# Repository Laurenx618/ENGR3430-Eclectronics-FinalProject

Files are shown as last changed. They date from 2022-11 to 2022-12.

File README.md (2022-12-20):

# ENGR3430-Eclectronics-FinalProject

## Description

This project is for the Eclectronics Final.

The final layout used was `no_connector`.

Here, we have a RPI2040 to connect to an ESP32-WROOM-32 (just for WIFI use) as well as an LCD screen in order to  connect to the internet, read someone's *Now Playing* information using the Spotify API Spotipy, and display the song on the screen. There is also a circuit for light detection, which is used to create a "light" and "dark" mode on screen. All of these are communicating with the RPI2040.

----
## Hardware Connections

* Microcontroller: RPI2040
* WiFi Module: ESP32-WROOM-32
* LCD Screen: 16x2 Serial LCD [(Amazon Link)](https://www.amazon.com/HiLetgo-HD44780-I2C1602-Interface-Backlight/dp/B07W5KC65S)

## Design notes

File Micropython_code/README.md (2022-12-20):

# Firmware

## Hardware Connections

* Microcontroller: RPI2040
* WiFi Module: ESP32-WROOM-32
* LCD Screen: 16x2 Serial LCD [Amazon Link](https://www.amazon.com/HiLetgo-HD44780-I2C1602-Interface-Backlight/dp/B07W5KC65S)

## Description

This folder includes both the tested CircuitPython and MicroPython code.

It includes the following libraries from the [CircuitPython Library Bundle](https://github.com/adafruit/Adafruit_CircuitPython_Bundle/releases):

* adafruit_bus_device
* adafruit_minimqtt
* adafruit_io
* adafruit_esp32_spi
* adafruit_requests.mpy

As well as this [ESP32SPI CircuitPython library from Adafruit](https://github.com/adafruit/Adafruit_CircuitPython_ESP32SPI).

------

Steps followed for the WIFI connection were according to this guide: [Quickstart IoT - Raspberry Pi Pico RP2040 with WIFI](https://learn.adafruit.com/quickstart-rp2040-pico-with-wifi-and-circuitpython/circuitpython-wifi)

Steps followed for the LCD screen driver included a lot of scaffolding from this video:[LCD Basics for the Pi Pico](https://youtu.be/B8Kr_3xHjqE).

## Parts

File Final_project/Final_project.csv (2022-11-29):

Collated Components:
Item | Qty | Reference(s) | Value | LibPart | Footprint | Datasheet | Digi-Key_Part
1 | 12 | C1, C2, C3, C4, C5, C6, C7, C10, C11, C15, C17, C18 | 0.1µF | Device:C | Capacitor_SMD:C_0603_1608Metric | ~ | CL10B104JB8NNNC
2 | 3 | C8, C9, C14 | 1µF | Device:C | Capacitor_SMD:C_0603_1608Metric | ~ | CL10B105KA8NNNC
3 | 3 | C12, C13, C16 | 10µF | Device:C | Capacitor_SMD:C_0603_1608Metric | ~ | GRM188R61E106KA73D
4 | 4 | D1, D3, D4, D5 | LED | Device:LED_Filled | Final_project:LTST-C170TBKT | ~ | LTST-C170TBKT
5 | 2 | D2, D6 | PWR | Device:LED_Filled | Final_project:LTST-C170TGKT | ~ | LTST-C170TGKT
6 | 1 | D7 | SWITCH | Device:LED_Filled | Final_project:LTST-C170TGKT | ~ | LTST-C170TGKT
7 | 1 | J1 | USB4105-GF-A | Eclectronics:USB4105-GF-A | Final_project:USB4105-GF-A |  | USB4105-GF-A
8 | 1 | J2 | Conn_01x04 | Connector_Generic:Conn_01x04 | Connector_PinSocket_2.54mm:PinSocket_1x04_P2.54mm_Horizontal | ~ | PPTC041LGBN-RC
9 | 1 | J4 | LEFT | Connector_Generic:Conn_01x20 | Connector_PinSocket_2.54mm:PinSocket_1x20_P2.54mm_Vertical | ~ | ~
10 | 1 | J5 | RIGHT | Connector_Generic:Conn_01x20 | Connector_PinSocket_2.54mm:PinSocket_1x20_P2.54mm_Vertical | ~ | ~
11 | 4 | R1, R2, R3, R4 | 5.1K | Device:R | Resistor_SMD:R_0603_1608Metric | ~ | ERJ-3EKF5101V
12 | 2 | R5, R6 | 27Ω | Device:R | Resistor_SMD:R_0603_1608Metric | ~
13 | 8 | R7, R8, R10, R11, R12, R13, R14, R17 | 1K | Device:R | Resistor_SMD:R_0603_1608Metric | ~ | RC0603FR-071KL
14 | 3 | R9, R15, R16 | 10K | Device:R | Resistor_SMD:R_0805_2012Metric | ~
15 | 1 | R18 | R_Photo | Device:R_Photo | Final_project:02-LDR4 | ~
16 | 1 | RV1 | LDR | Device:R_Potentiometer | Final_project:TRIM_T73YU103KT20 | ~ | TRIM_T73YU103KT20
17 | 1 | S1 | RST | Eclectronics:SW | Final_project:KXT321LHS |  | KXT321LHS
18 | 1 | S2 | BOOT | Eclectronics:SW | Final_project:KXT321LHS |  | KXT321LHS
19 | 1 | U1 | RP2040 | Eclectronics:RP2040 | Final_project:RP2040 | https://datasheets.raspberrypi.com/rp2040/rp2040-datasheet.pdf | MCP1702T-3302E&slash_CB
20 | 1 | U2 | MCP1702T-3302E_CB | Eclectronics:MCP1702T-3302E_CB | Final_project:MCP1702T-3302E&slash_CB |  | MIC_WSON-8-M
21 | 1 | U3 | W25Q128JV | Eclectronics:W25Q128JV | Final_project:MIC_WSON-8-M |  | X
22 | 1 | U4 | ESP32-WROOM-32 | ESP32-WROOM-32:ESP32-WROOM-32 | MODULE_ESP32-WROOM-32 | https://www.espressif.com/sites/default/files/documentation/esp32-wroom-32_datasheet_en.pdf | LM393D
23 | 1 | U5 | LM393D | pspice:OPAMP | Final_project:LM393D | ~ | CSTNE
24 | 1 | Y1 | 12MHz | Eclectronics:Crystal | Final_project:CSTNE

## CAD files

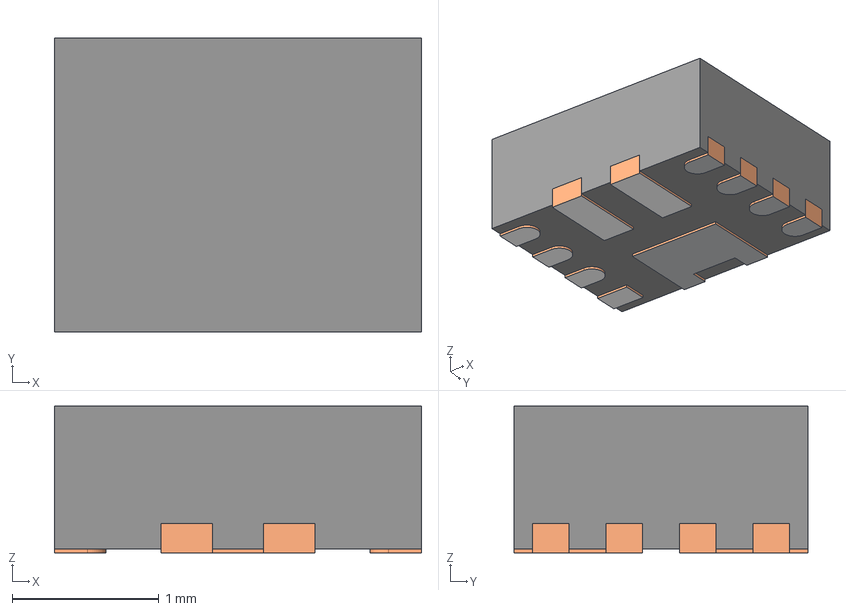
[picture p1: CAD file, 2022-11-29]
Final_project/3D/RNR0011A.stp
2.50 x 2.00 x 1.00 mm
FRAME-RNR0011A
BODY-QFN
PIN1-ID

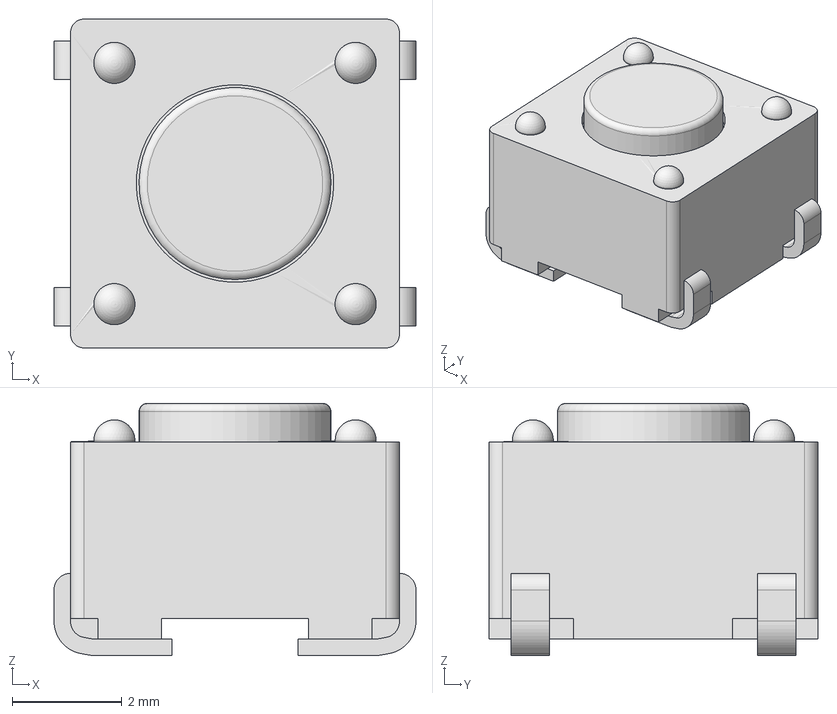
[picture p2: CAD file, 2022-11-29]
Final_project/3D/TL3301NFxxxxJ.stp
6.60 x 6.00 x 4.60 mm

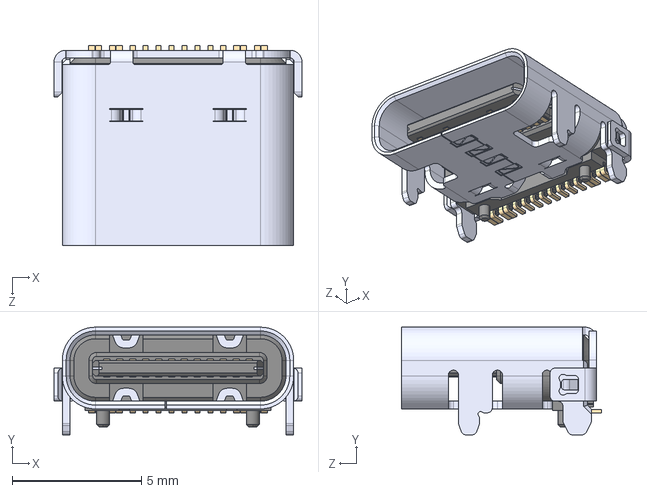
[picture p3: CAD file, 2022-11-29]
Final_project/3D/USB4105-GF-A.step
9.58 x 4.16 x 7.71 mm

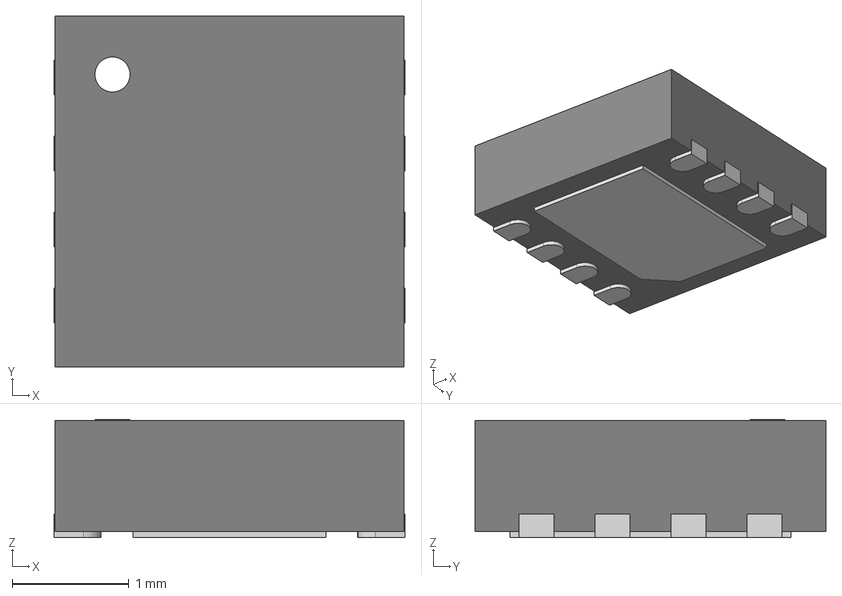
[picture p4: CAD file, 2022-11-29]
Final_project/3D/DFN8_3x3_0.65.step
3.00 x 3.00 x 1.01 mm

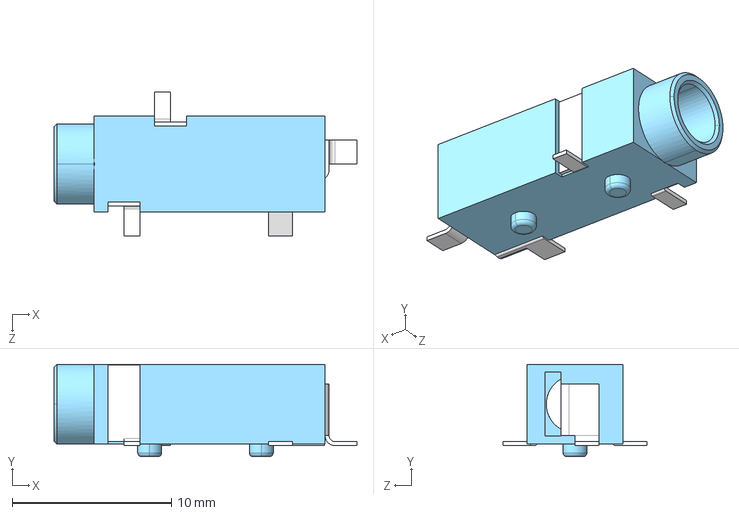
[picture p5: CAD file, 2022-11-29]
Final_project/3D/SJ-3524-SMT-TR-BE.step
19.0 x 5.80 x 9.00 mm

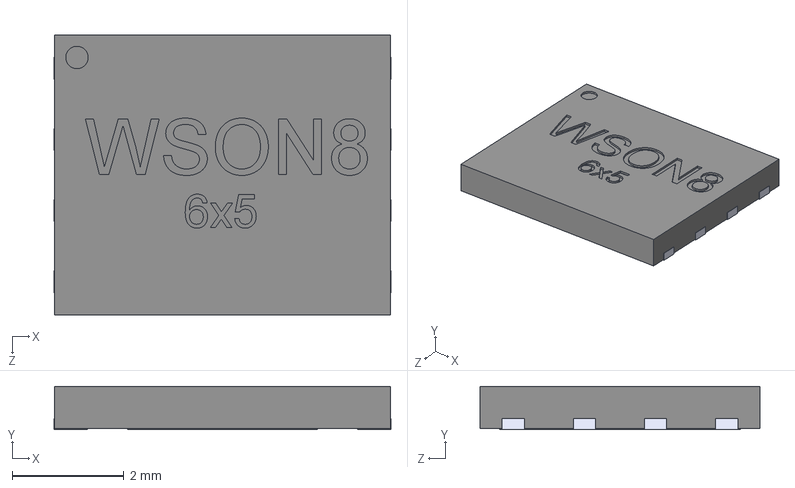
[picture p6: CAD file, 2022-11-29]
Final_project/3D/WSON8-6x5.STEP
6.02 x 0.77 x 5.00 mm

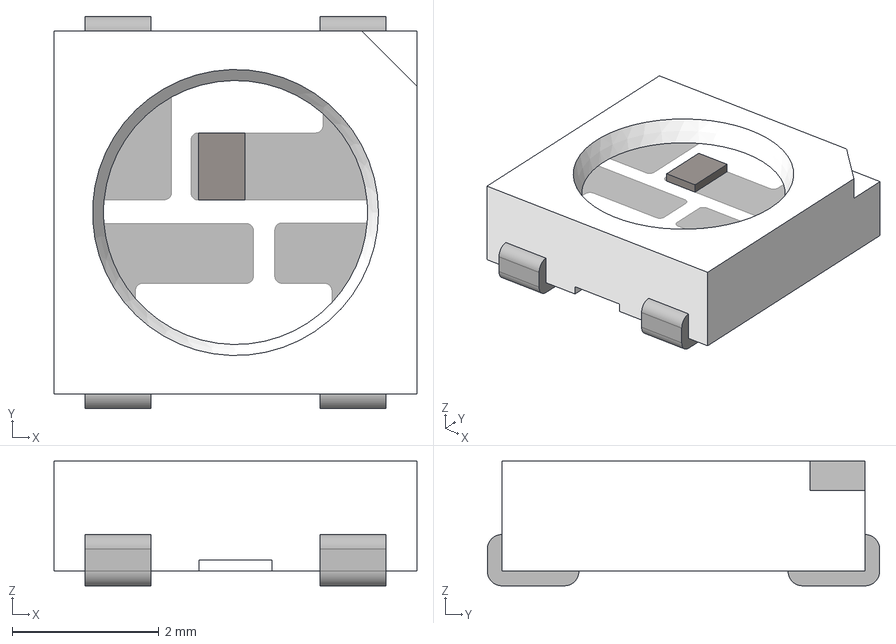
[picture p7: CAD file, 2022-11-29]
Final_project/3D/WS2812_RGB_LED_updated.stp
4.95 x 5.35 x 1.70 mm

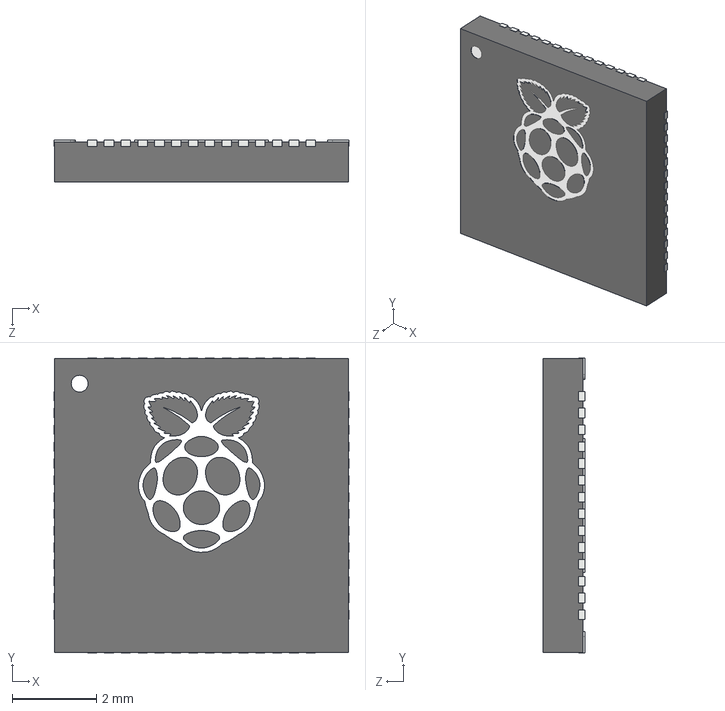
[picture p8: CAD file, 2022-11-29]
Final_project/3D/RP2040_QFN_PACKAGE.STEP
7.02 x 7.02 x 1.00 mm

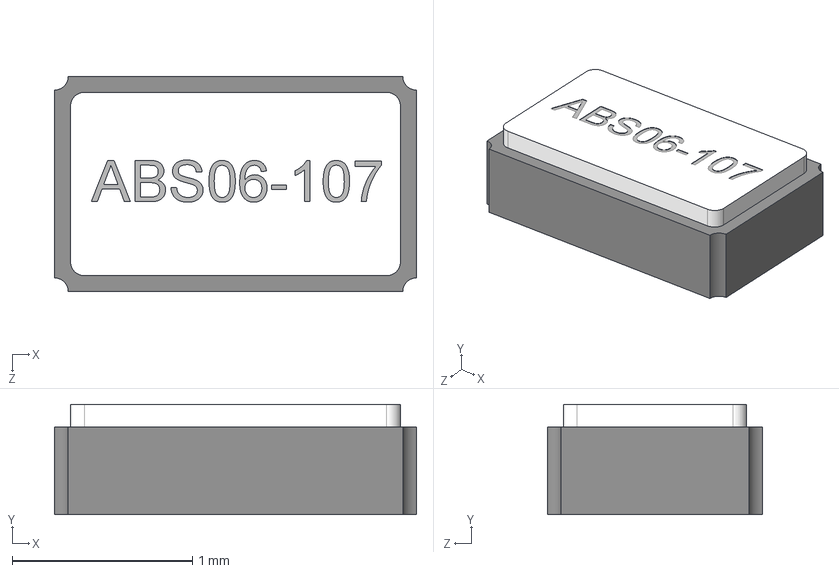
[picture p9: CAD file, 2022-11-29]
Final_project/3D/ABS06-107.STP
2.01 x 0.612 x 1.19 mm

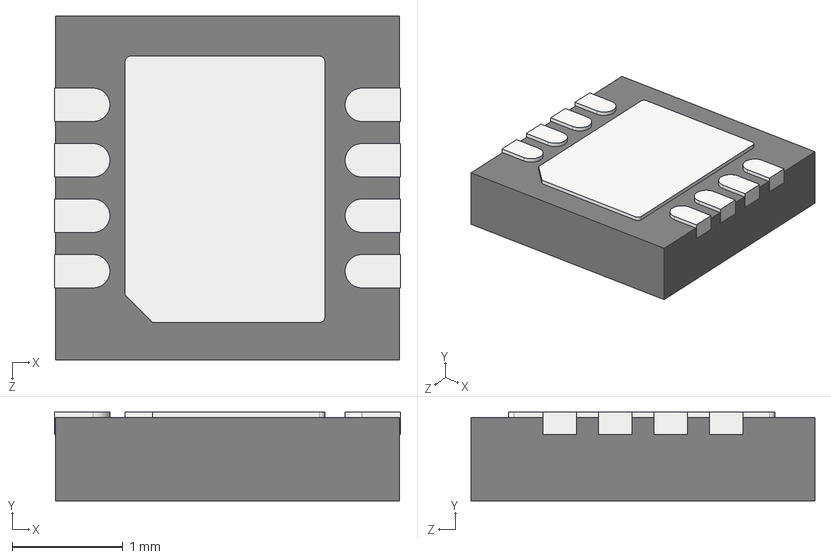
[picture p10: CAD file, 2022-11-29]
Final_project/3D/DFN-8-3x3-0_5.STEP
3.12 x 0.8 x 3.10 mm
User Library-My-DFN-8-3x3-0.5_Part 11
User Library-My-DFN-8-3x3-0.5_Body
User Library-My-DFN-8-3x3-0.5_14
User Library-My-DFN-8-3x3-0.5_13
User Library-My-DFN-8-3x3-0.5_2
User Library-My-DFN-8-3x3-0.5_1
User Library-My-DFN-8-3x3-0.5_11
User Library-My-DFN-8-3x3-0.5_3
User Library-My-DFN-8-3x3-0.5_12
User Library-My-DFN-8-3x3-0.5_4
User Library-My-DFN-8-3x3-0.5_TP

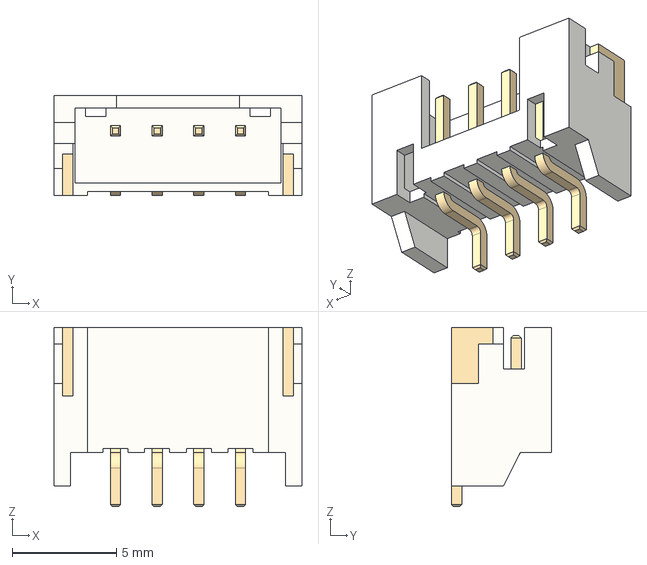
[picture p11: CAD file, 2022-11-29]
Final_project/3D/S4B-PH-SM4-TB.stp
11.9 x 4.80 x 8.60 mm

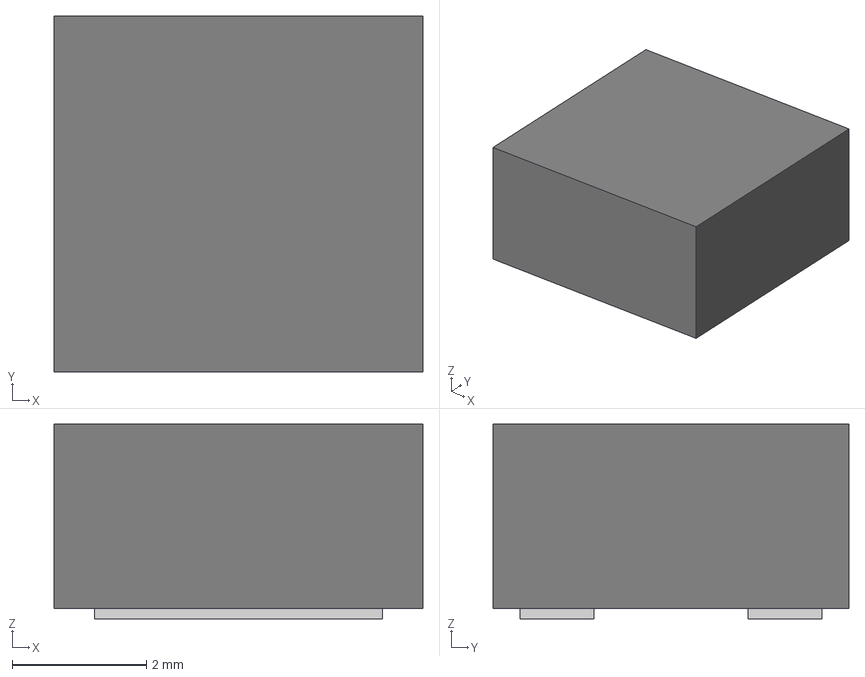
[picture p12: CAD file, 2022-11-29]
Final_project/3D/PA5003.182NLT.step
5.50 x 5.30 x 2.90 mm

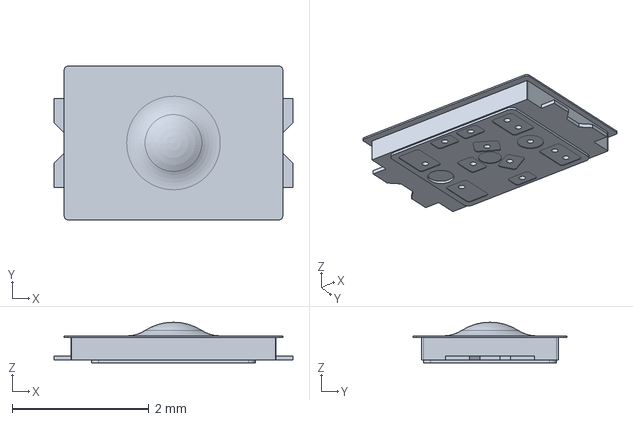
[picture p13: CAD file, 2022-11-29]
Final_project/3D/KXT321LHS.stp
3.50 x 2.25 x 0.595 mm

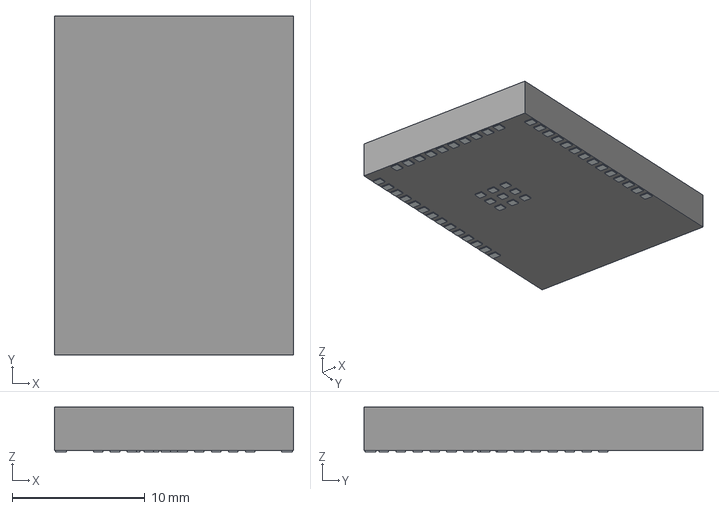
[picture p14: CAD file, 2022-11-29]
Final_project/3D/ESP32-WROOM-32D-N4.stp
18.0 x 25.5 x 3.35 mm
Pins

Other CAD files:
Final_project/3D/TL3301AFxxxxJ.stp
Final_project/3D/UFQFPN48.stp
Final_project/3D/CUI_SDS-50J.step
Final_project/3D/ABM10.STP
Final_project/3D/3382g-001-xxx.stp
Final_project/3D/CSTNE.step
Final_project/3D/QFN-32_5x5.stp
Final_project/3D/WS2812-2020.STEP

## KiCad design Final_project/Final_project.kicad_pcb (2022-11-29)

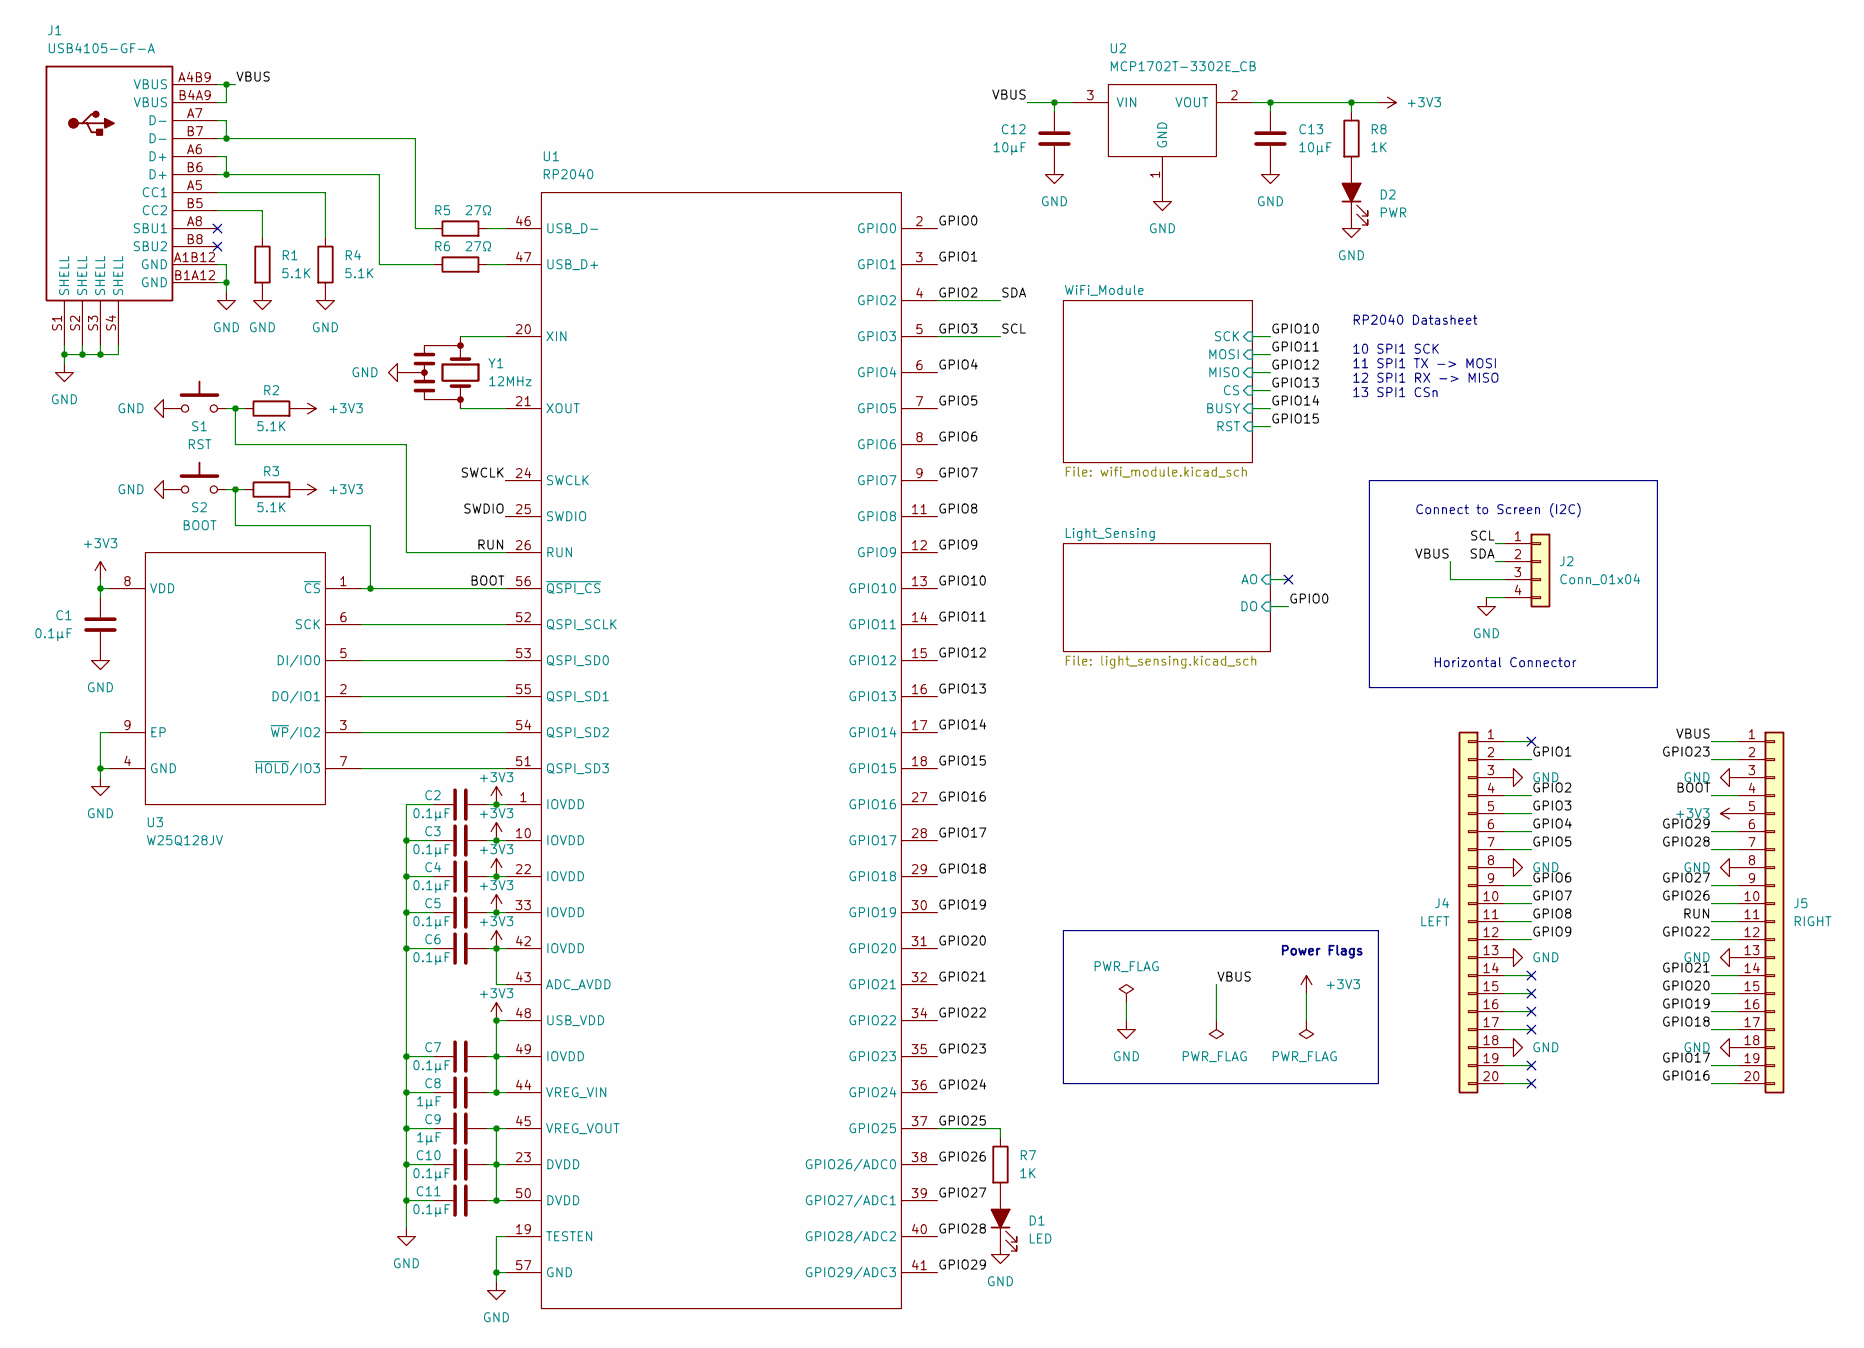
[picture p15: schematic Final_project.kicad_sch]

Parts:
C1, C2, C3: 0.1µF; C_0603_1608Metric; Digi-Key_Part CL10B104JB8NNNC
C4, C5, C6, C7, C10, C11: 0.1µF; C_0603_1608Metric
C8: 1µF; C_0603_1608Metric; Digi-Key_Part CL10B105KA8NNNC
C9: 1µF; C_0603_1608Metric
C12, C13: 10µF; C_0603_1608Metric; Digi-Key_Part GRM188R61E106KA73D
D1: LED; LTST-C170TBKT
D2: PWR; LTST-C170TGKT
J1: USB4105-GF-A
J2: Conn_01x04; PinSocket_1x04_P2.54mm_Horizontal
J4: LEFT; PinSocket_1x20_P2.54mm_Vertical
J5: RIGHT; PinSocket_1x20_P2.54mm_Vertical
R1: 5.1K; R_0603_1608Metric
R2, R4: 5.1K; R_0603_1608Metric; Digi-Key_Part ERJ-3EKF5101V
R3: 5.1K; R_0603_1608Metric; Digi-Key_Part ERJ-3EKF5101VERJ-3EKF5101V
R5: 27Ω; R_0603_1608Metric; Part RC0603FR-071KL
R6: 27Ω; R_0603_1608Metric
R7, R8: 1K; R_0603_1608Metric; Digi-Key_Part RC0603FR-071KL
S1: RST; KXT321LHS
S2: BOOT; KXT321LHS
U1: RP2040
U2: MCP1702T-3302E_CB; MCP1702T-3302E&slash_CB
U3: W25Q128JV; MIC_WSON-8-M
Y1: 12MHz; CSTNE

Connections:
+3V3: C1.2, C2.1, C3.1, C4.1, C5.1, C6.1, C7.1, C8.1, C13.1, J5.5, R2.2, R3.2, R8.1, U1.1 (IOVDD), U1.10 (IOVDD), U1.22 (IOVDD), U1.33 (IOVDD), U1.42 (IOVDD), U1.43 (ADC_AVDD), U1.44 (VREG_VIN), U1.48 (USB_VDD), U1.49 (IOVDD), U2.2 (VOUT), U3.8 (VDD); also elsewhere on the board
/BOOT: J5.4, R3.1, S2.2, U1.56 (~QSPI_CS), U3.1 (~CS)
/GPIO0: U1.2 (GPIO0); also elsewhere on the board
/GPIO1: J4.2, U1.3 (GPIO1)
/GPIO2: J2.2, J4.4, U1.4 (GPIO2)
/GPIO3: J2.1, J4.5, U1.5 (GPIO3)
/GPIO4: J4.6, U1.6 (GPIO4)
/GPIO5: J4.7, U1.7 (GPIO5)
/GPIO6: J4.9, U1.8 (GPIO6)
/GPIO7: J4.10, U1.9 (GPIO7)
/GPIO8: J4.11, U1.11 (GPIO8)
/GPIO9: J4.12, U1.12 (GPIO9)
/GPIO10: U1.13 (GPIO10); also elsewhere on the board
/GPIO11: U1.14 (GPIO11); also elsewhere on the board
/GPIO12: U1.15 (GPIO12); also elsewhere on the board
/GPIO13: U1.16 (GPIO13); also elsewhere on the board
/GPIO14: U1.17 (GPIO14); also elsewhere on the board
/GPIO15: U1.18 (GPIO15); also elsewhere on the board
/GPIO16: J5.20, U1.27 (GPIO16)
/GPIO17: J5.19, U1.28 (GPIO17)
/GPIO18: J5.17, U1.29 (GPIO18)
/GPIO19: J5.16, U1.30 (GPIO19)
/GPIO20: J5.15, U1.31 (GPIO20)
/GPIO21: J5.14, U1.32 (GPIO21)
/GPIO22: J5.12, U1.34 (GPIO22)
/GPIO23: J5.2, U1.35 (GPIO23)
/GPIO24: U1.36 (GPIO24)
/GPIO25: R7.1, U1.37 (GPIO25)
/GPIO26: J5.10, U1.38 (GPIO26/ADC0)
/GPIO27: J5.9, U1.39 (GPIO27/ADC1)
/GPIO28: J5.7, U1.40 (GPIO28/ADC2)
/GPIO29: J5.6, U1.41 (GPIO29/ADC3)
/RUN: J5.11, R2.1, S1.2, U1.26 (RUN)
/SWCLK: U1.24 (SWCLK)
/SWDIO: U1.25 (SWDIO)
/VBUS: C12.2, J1.A4B9 (VBUS), J1.B4A9 (VBUS), J2.3, J5.1, U2.3 (VIN)
GND: C1.1, C2.2, C3.2, C4.2, C5.2, C6.2, C7.2, C8.2, C9.2, C10.2, C11.2, C12.1, C13.2, D1.1 (K), D2.1 (K), J1.A1B12 (GND), J1.B1A12 (GND), J1.S1 (SHELL), J1.S2 (SHELL), J1.S3 (SHELL), J1.S4 (SHELL), J2.4, J4.3, J4.8, J4.13, J4.18, J5.3, J5.8, J5.13, J5.18, R1.2, R4.2, S1.1, S2.1, U1.19 (TESTEN), U1.57 (GND), U2.1 (GND), U3.4 (GND), U3.9 (EP), Y1.2; also elsewhere on the board
unnamed: C9.1, C10.1, C11.1, U1.23 (DVDD), U1.45 (VREG_VOUT), U1.50 (DVDD)
unnamed: D1.2 (A), R7.2
unnamed: D2.2 (A), R8.2
unnamed: J1.A5 (CC1), R4.1
unnamed: J1.A6 (D+), J1.B6 (D+), R6.1
unnamed: J1.A7 (D-), J1.B7 (D-), R5.1
unnamed: J1.B5 (CC2), R1.1
unnamed: R5.2, U1.46 (USB_D-)
unnamed: R6.2, U1.47 (USB_D+)
unnamed: U1.20 (XIN), Y1.1
unnamed: U1.21 (XOUT), Y1.3
unnamed: U1.51 (QSPI_SD3), U3.7 (~HOLD/IO3)
unnamed: U1.52 (QSPI_SCLK), U3.6 (SCK)
unnamed: U1.53 (QSPI_SD0), U3.5 (DI/IO0)
unnamed: U1.54 (QSPI_SD2), U3.3 (~WP/IO2)
unnamed: U1.55 (QSPI_SD1), U3.2 (DO/IO1)

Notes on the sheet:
Connect to Screen (I2C)
Horizontal Connector
Power Flags
RP2040 Datasheet 10 SPI1 SCK 11 SPI1 TX -> MOSI 12 SPI1 RX -> MISO 13 SPI1 CSn

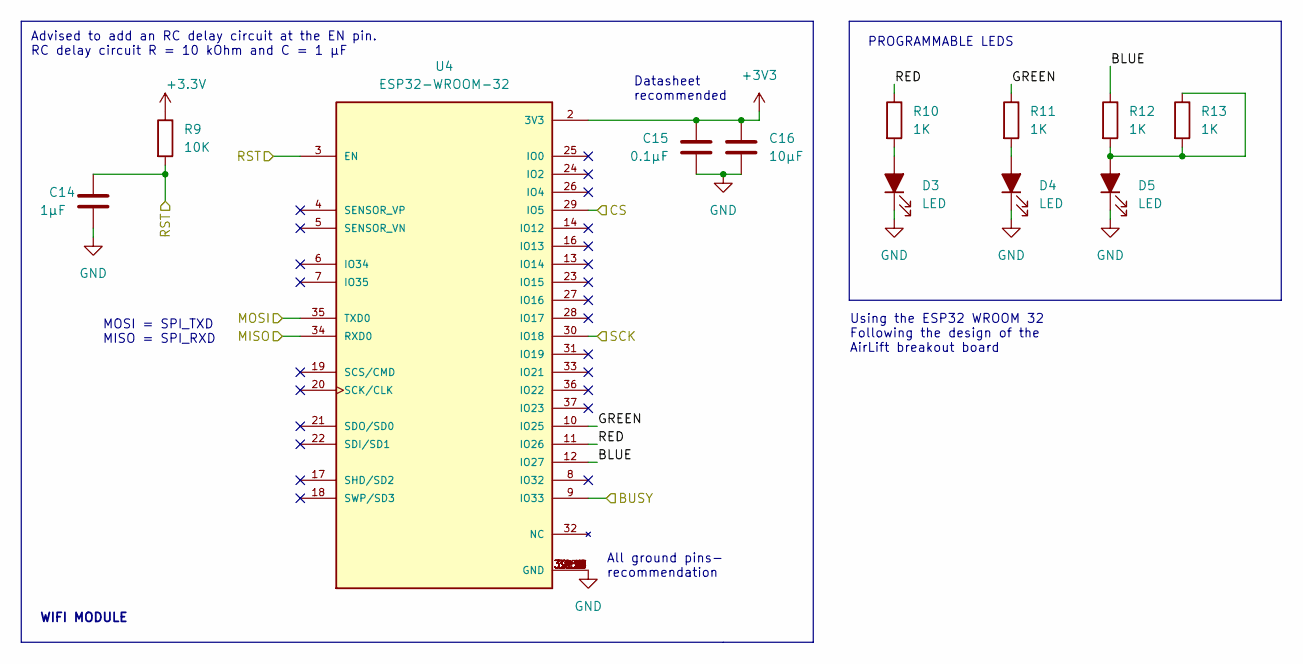
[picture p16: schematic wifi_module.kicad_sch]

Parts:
C14: 1µF; C_0603_1608Metric; Digi-Key_Part CL10B105KA8NNNC
C15: 0.1µF; C_0603_1608Metric; Digi-Key_Part CL10B105KA8NNNC
C16: 10µF; C_0603_1608Metric; Digi-Key_Part GRM188R61E106KA73D
D3, D4, D5: LED; LTST-C170TBKT
R9: 10K; R_0805_2012Metric
R10, R11, R12: 1K; R_0603_1608Metric; Digi-Key_Part RC0603FR-071KL
R13: 1K; R_0603_1608Metric
U4: ESP32-WROOM-32; MODULE_ESP32-WROOM-32; PARTREV 2.9

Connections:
+3.3V: R9.1
+3V3: C15.1, C16.1, U4.2 (3V3); also elsewhere on the board
/GPIO10: U4.30 (IO18); also elsewhere on the board
/GPIO11: U4.35 (TXD0); also elsewhere on the board
/GPIO12: U4.34 (RXD0); also elsewhere on the board
/GPIO13: U4.29 (IO5); also elsewhere on the board
/GPIO14: U4.9 (IO33); also elsewhere on the board
/GPIO15: C14.2, R9.2, U4.3 (EN); also elsewhere on the board
/WiFi_Module/BLUE: R12.1, U4.12 (IO27)
/WiFi_Module/GREEN: R11.1, U4.10 (IO25)
/WiFi_Module/RED: R10.1, U4.11 (IO26)
GND: C14.1, C15.2, C16.2, D3.1 (K), D4.1 (K), D5.1 (K), U4.1 (GND), U4.15 (GND), U4.38 (GND), U4.39_1 (GND), U4.39_2 (GND), U4.39_3 (GND), U4.39_4 (GND), U4.39_5 (GND), U4.39_6 (GND), U4.39_7 (GND), U4.39_8 (GND), U4.39_9 (GND), U4.39_10 (GND), U4.39_11 (GND), U4.39_12 (GND), U4.39_13 (GND), U4.39_14 (GND), U4.39_15 (GND), U4.39_16 (GND), U4.39_17 (GND), U4.39_18 (GND), U4.39_19 (GND), U4.39_20 (GND), U4.39_21 (GND); also elsewhere on the board
unnamed: D3.2 (A), R10.2
unnamed: D4.2 (A), R11.2
unnamed: D5.2 (A), R12.2, R13.1, R13.2

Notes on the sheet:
PROGRAMMABLE LEDS
WIFI MODULE
All ground pins- recommendation
Datasheet recommended
MOSI = SPI_TXD MISO = SPI_RXD
Using the ESP32 WROOM 32 Following the design of the AirLift breakout board
Advised to add an RC delay circuit at the EN pin. RC delay circuit R = 10 kOhm and C = 1 μF

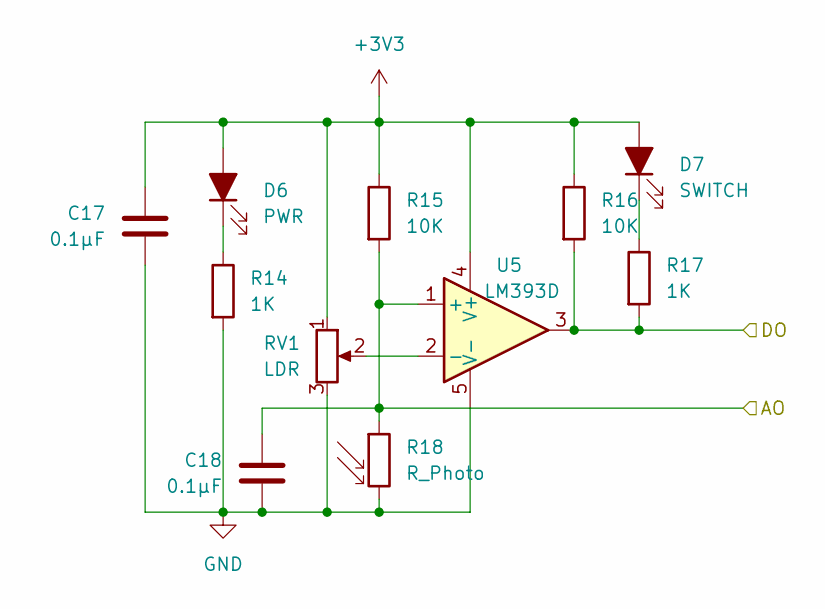
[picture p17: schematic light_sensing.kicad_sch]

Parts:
C17, C18: 0.1µF; C_0603_1608Metric; Digi-Key_Part CL10B104JB8NNNC
D6: PWR; LTST-C170TGKT
D7: SWITCH; LTST-C170TGKT
R14, R17: 1K; R_0603_1608Metric; Digi-Key_Part RC0603FR-071KL
R15, R16: 10K; R_0805_2012Metric
R18: R_Photo; 02-LDR4
RV1: LDR; TRIM_T73YU103KT20
U5: LM393D

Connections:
+3V3: C17.2, D6.2 (A), D7.2 (A), R15.1, R16.1, RV1.1, U5.4 (V+); also elsewhere on the board
/GPIO0: R16.2, R17.2, U5.3; also elsewhere on the board
/Light_Sensing/AO: C18.2, R15.2, R18.1, U5.1 (+)
GND: C17.1, C18.1, R14.2, R18.2, RV1.3, U5.5 (V-); also elsewhere on the board
unnamed: D6.1 (K), R14.1
unnamed: D7.1 (K), R17.1
unnamed: RV1.2, U5.2 (-)

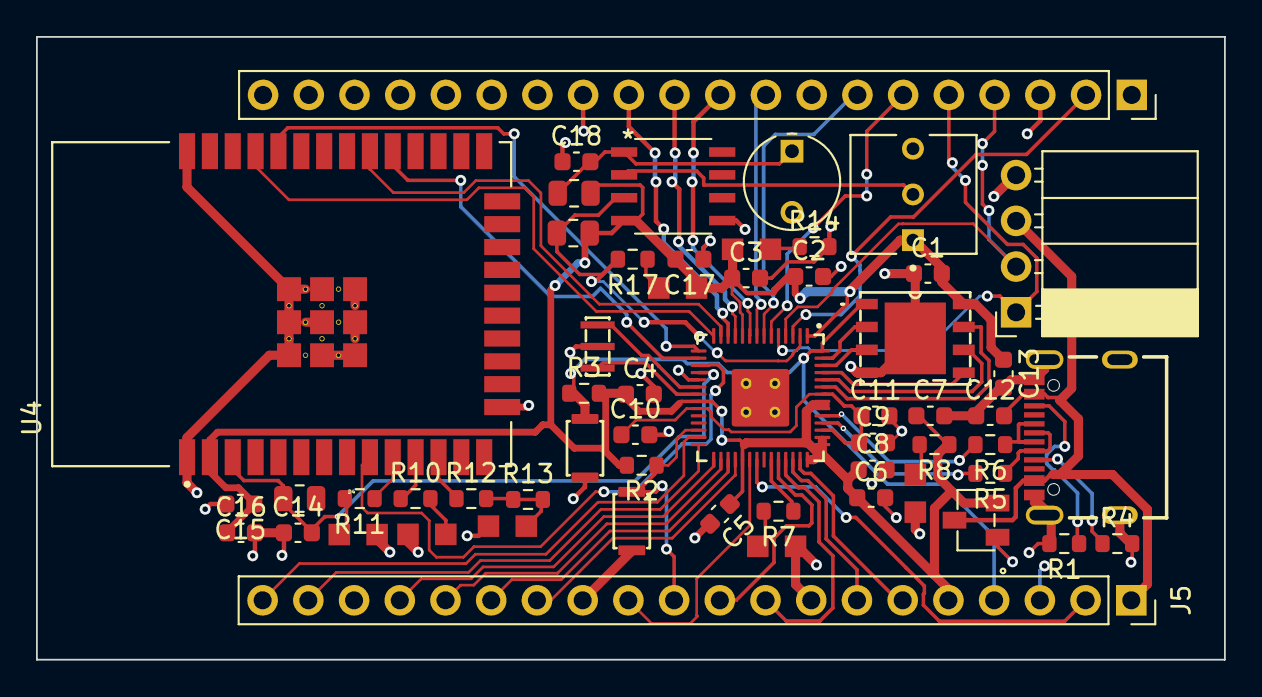
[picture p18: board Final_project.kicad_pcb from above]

Board: 2 copper layers, 66.0 x 34.6 mm, 56 parts (0 on the bottom side), 60 nets.

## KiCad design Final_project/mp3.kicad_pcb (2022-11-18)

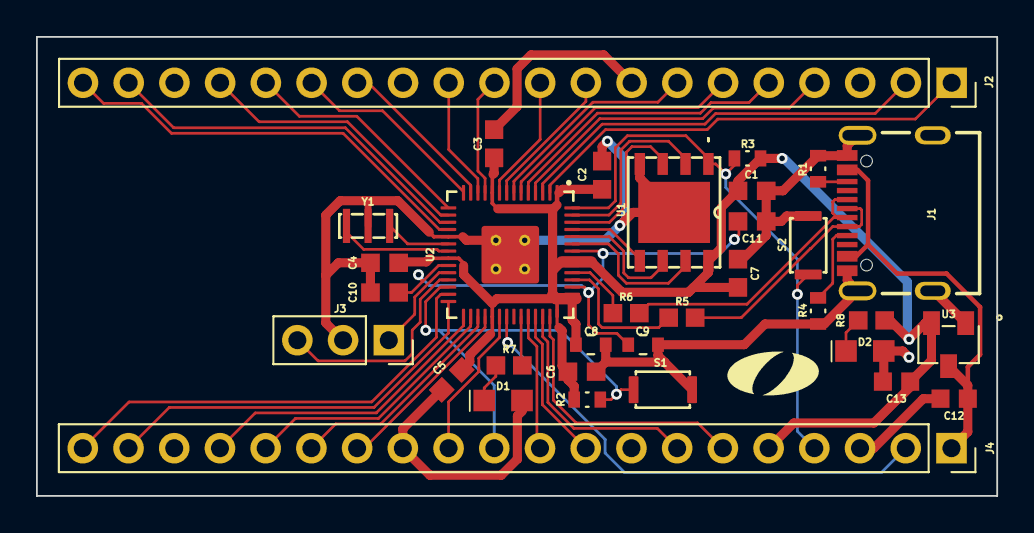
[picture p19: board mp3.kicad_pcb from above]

Board: 2 copper layers, 53.3 x 25.5 mm, 34 parts (0 on the bottom side), 52 nets.

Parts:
C1, C2, C3, C4, C5, C6, C7, C10, C11: 0.1µF; CL10B104JB8NNNC
C8, C9: 1µF; CL10B105KA8NNNC
C12, C13: 10µF; GRM188R61E106KA73D
D1: LED; LTST-C170TBKT
D2: PWR; LTST-C170TGKT
J1: USB4105-GF-A
J2: LEFT; PinSocket_1x20_P2.54mm_Vertical
J3: DEBUG; PinSocket_1x03_P2.54mm_Vertical
J4: RIGHT; PinSocket_1x20_P2.54mm_Vertical
OlinLogoSm: G***; OlinLogoSm
R1, R2, R3, R4: 5.1K; RES_ERJ3EKF5101V
R5, R6: 27Ω; RC0603FR-071KL
R7, R8: 1K; RC0603FR-071KL
S1: RST; KXT321LHS
S2: BOOT; KXT321LHS
U1: W25Q128JV; MIC_WSON-8-M
U2: RP2040
U3: MCP1702T-3302E_CB; MCP1702T-3302E&slash_CB
Y1: 12MHz; CSTNE

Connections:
+3V3: C1.2, C2.1, C3.1, C4.1, C5.1, C6.1, C7.1, C8.1, C13.1, J4.5, R2.2, R3.2, R8.1, U1.8 (VDD), U2.1 (IOVDD), U2.10 (IOVDD), U2.22 (IOVDD), U2.33 (IOVDD), U2.42 (IOVDD), U2.43 (ADC_AVDD), U2.44 (VREG_VIN), U2.48 (USB_VDD), U2.49 (IOVDD), U3.2 (VOUT)
/BOOT: J4.4, R3.1, S2.2, U1.1 (~CS), U2.56 (~QSPI_CS)
/GPIO0: J2.1, U2.2 (GPIO0)
/GPIO1: J2.2, U2.3 (GPIO1)
/GPIO2: J2.4, U2.4 (GPIO2)
/GPIO3: J2.5, U2.5 (GPIO3)
/GPIO4: J2.6, U2.6 (GPIO4)
/GPIO5: J2.7, U2.7 (GPIO5)
/GPIO6: J2.9, U2.8 (GPIO6)
/GPIO7: J2.10, U2.9 (GPIO7)
/GPIO8: J2.11, U2.11 (GPIO8)
/GPIO9: J2.12, U2.12 (GPIO9)
/GPIO10: J2.14, U2.13 (GPIO10)
/GPIO11: J2.15, U2.14 (GPIO11)
/GPIO12: J2.16, U2.15 (GPIO12)
/GPIO13: J2.17, U2.16 (GPIO13)
/GPIO14: J2.19, U2.17 (GPIO14)
/GPIO15: J2.20, U2.18 (GPIO15)
/GPIO16: J4.20, U2.27 (GPIO16)
/GPIO17: J4.19, U2.28 (GPIO17)
/GPIO18: J4.17, U2.29 (GPIO18)
/GPIO19: J4.16, U2.30 (GPIO19)
/GPIO20: J4.15, U2.31 (GPIO20)
/GPIO21: J4.14, U2.32 (GPIO21)
/GPIO22: J4.12, U2.34 (GPIO22)
/GPIO23: J4.2, U2.35 (GPIO23)
/GPIO25: R7.1, U2.37 (GPIO25)
/GPIO26: J4.10, U2.38 (GPIO26/ADC0)
/GPIO27: J4.9, U2.39 (GPIO27/ADC1)
/GPIO28: J4.7, U2.40 (GPIO28/ADC2)
/GPIO29: J4.6, U2.41 (GPIO29/ADC3)
/RUN: J4.11, R2.1, S1.2, U2.26 (RUN)
/SWCLK: J3.1, U2.24 (SWCLK)
/SWDIO: J3.3, U2.25 (SWDIO)
/VBUS: C12.2, J1.A4B9 (VBUS), J1.B4A9 (VBUS), J4.1, U3.3 (VIN)
GND: C1.1, C2.2, C3.2, C4.2, C5.2, C6.2, C7.2, C8.2, C9.2, C10.2, C11.2, C12.1, C13.2, D1.1 (K), D2.1 (K), J1.A1B12 (GND), J1.B1A12 (GND), J1.S1 (SHELL), J1.S2 (SHELL), J1.S3 (SHELL), J1.S4 (SHELL), J2.3, J2.8, J2.13, J2.18, J3.2, J4.3, J4.8, J4.13, J4.18, R1.2, R4.2, S1.1, S2.1, U1.4 (GND), U1.9 (EP), U2.19 (TESTEN), U2.57 (GND), U3.1 (GND), Y1.2
unnamed: C9.1, C10.1, C11.1, U2.23 (DVDD), U2.45 (VREG_VOUT), U2.50 (DVDD)
unnamed: D1.2 (A), R7.2
unnamed: D2.2 (A), R8.2
unnamed: J1.A5 (CC1), R4.1
unnamed: J1.A6 (D+), J1.B6 (D+), R6.1
unnamed: J1.A7 (D-), J1.B7 (D-), R5.1
unnamed: J1.B5 (CC2), R1.1
unnamed: R5.2, U2.46 (USB_D-)
unnamed: R6.2, U2.47 (USB_D+)
unnamed: U1.2 (DO/IO1), U2.55 (QSPI_SD1)
unnamed: U1.3 (~WP/IO2), U2.54 (QSPI_SD2)
unnamed: U1.5 (DI/IO0), U2.53 (QSPI_SD0)
unnamed: U1.6 (SCK), U2.52 (QSPI_SCLK)
unnamed: U1.7 (~HOLD/IO3), U2.51 (QSPI_SD3)
unnamed: U2.20 (XIN), Y1.1
unnamed: U2.21 (XOUT), Y1.3

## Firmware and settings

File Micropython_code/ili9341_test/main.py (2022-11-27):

from machine import Pin, SPI

import time
import ustruct
import glcdfont
import framebuf
from micropython import const

_RDDSDR = const(0x0f) # Read Display Self-Diagnostic Result
_SLPOUT = const(0x11) # Sleep Out
_GAMSET = const(0x26) # Gamma Set
_DISPOFF = const(0x28) # Display Off
_DISPON = const(0x29) # Display On
_CASET = const(0x2a) # Column Address Set
_PASET = const(0x2b) # Page Address Set
_RAMWR = const(0x2c) # Memory Write
_RAMRD = const(0x2e) # Memory Read
_MADCTL = const(0x36) # Memory Access Control
_VSCRSADD = const(0x37) # Vertical Scrolling Start Address
_PIXSET = const(0x3a) # Pixel Format Set
_PWCTRLA = const(0xcb) # Power Control A
_PWCRTLB = const(0xcf) # Power Control B
_DTCTRLA = const(0xe8) # Driver Timing Control A
_DTCTRLB = const(0xea) # Driver Timing Control B
_PWRONCTRL = const(0xed) # Power on Sequence Control
_PRCTRL = const(0xf7) # Pump Ratio Control
_PWCTRL1 = const(0xc0) # Power Control 1
_PWCTRL2 = const(0xc1) # Power Control 2
_VMCTRL1 = const(0xc5) # VCOM Control 1
_VMCTRL2 = const(0xc7) # VCOM Control 2
_FRMCTR1 = const(0xb1) # Frame Rate Control 1
_DISCTRL = const(0xb6) # Display Function Control
_ENA3G = const(0xf2) # Enable 3G
_PGAMCTRL = const(0xe0) # Positive Gamma Control
_NGAMCTRL = const(0xe1) # Negative Gamma Control

_CHUNK = const(1024) #maximum number of pixels per spi write

def color565(r, g, b):
    return (r & 0xf8) << 8 | (g & 0xfc) << 3 | b >> 3

class ILI9341:

    def __init__(self, spi, cs, dc, rst, w, h, r):
        self.spi = spi
        self.cs = cs
        self.dc = dc
        self.rst = rst
        self._init_width = w
        self._init_height = h
        self.width = w
        self.height = h
        self.rotation = r
        self.cs.init(self.cs.OUT, value=1)
        self.dc.init(self.dc.OUT, value=0)
        self.rst.init(self.rst.OUT, value=0)
        self.reset()
        self.init()
        self._scroll = 0
        self._buf = bytearray(_CHUNK * 2)
        self._colormap = bytearray(b'\x00\x00\xFF\xFF') #default white foregraound, black background
        self._x = 0
        self._y = 0
        self._font = glcdfont
        self.scrolling = False

    def set_color(self,fg,bg):
        self._colormap[0] = bg>>8
        self._colormap[1] = bg & 255
        self._colormap[2] = fg>>8
        self._colormap[3] = fg & 255

    def set_pos(self,x,y):
        self._x = x
        self._y = y

    def reset_scroll(self):
        self.scrolling = False
        self._scroll = 0
        self.scroll(0)

    def set_font(self, font):
        self._font = font

    def init(self):
        for command, data in (
            (_RDDSDR, b"\x03\x80\x02"),
            (_PWCRTLB, b"\x00\xc1\x30"),
            (_PWRONCTRL, b"\x64\x03\x12\x81"),
            (_DTCTRLA, b"\x85\x00\x78"),
            (_PWCTRLA, b"\x39\x2c\x00\x34\x02"),
            (_PRCTRL, b"\x20"),
            (_DTCTRLB, b"\x00\x00"),
            (_PWCTRL1, b"\x23"),
            (_PWCTRL2, b"\x10"),
            (_VMCTRL1, b"\x3e\x28"),
            (_VMCTRL2, b"\x86")):
            self._write(command, data)

        if self.rotation == 0:                  # 0 deg
            self._write(_MADCTL, b"\x48")
            self.width = self._init_height
            self.height = self._init_width
        elif self.rotation == 1:                # 90 deg
            self._write(_MADCTL, b"\x28")
            self.width = self._init_width
            self.height = self._init_height
        elif self.rotation == 2:                # 180 deg
            self._write(_MADCTL, b"\x88")
            self.width = self._init_height
            self.height = self._init_width
        elif self.rotation == 3:                # 270 deg
            self._write(_MADCTL, b"\xE8")
            self.width = self._init_width
            self.height = self._init_height
        elif self.rotation == 4:                # Mirrored + 0 deg
            self._write(_MADCTL, b"\xC8")
            self.width = self._init_height
            self.height = self._init_width
        elif self.rotation == 5:                # Mirrored + 90 deg
            self._write(_MADCTL, b"\x68")
            self.width = self._init_width
            self.height = self._init_height
        elif self.rotation == 6:                # Mirrored + 180 deg
            self._write(_MADCTL, b"\x08")
            self.width = self._init_height
            self.height = self._init_width
        elif self.rotation == 7:                # Mirrored + 270 deg
            self._write(_MADCTL, b"\xA8")
            self.width = self._init_width
            self.height = self._init_height
        else:
            self._write(_MADCTL, b"\x08")

        for command, data in (
            (_PIXSET, b"\x55"),
            (_FRMCTR1, b"\x00\x18"),
            (_DISCTRL, b"\x08\x82\x27"),
            (_ENA3G, b"\x00"),
            (_GAMSET, b"\x01"),
            (_PGAMCTRL, b"\x0f\x31\x2b\x0c\x0e\x08\x4e\xf1\x37\x07\x10\x03\x0e\x09\x00"),
            (_NGAMCTRL, b"\x00\x0e\x14\x03\x11\x07\x31\xc1\x48\x08\x0f\x0c\x31\x36\x0f")):
            self._write(command, data)
        self._write(_SLPOUT)
        time.sleep_ms(120)
        self._write(_DISPON)

    def reset(self):
        self.rst(0)
        time.sleep_ms(50)
        self.rst(1)
        time.sleep_ms(50)

    def _write(self, command, data=None):
        self.dc(0)
        self.cs(0)
        self.spi.write(bytearray([command]))
        self.cs(1)
        if data is not None:
            self._data(data)

    def _data(self, data):
        self.dc(1)
        self.cs(0)
        self.spi.write(data)
        self.cs(1)

    def _writeblock(self, x0, y0, x1, y1, data=None):
        self._write(_CASET, ustruct.pack(">HH", x0, x1))
        self._write(_PASET, ustruct.pack(">HH", y0, y1))
        self._write(_RAMWR, data)

    def _readblock(self, x0, y0, x1, y1, data=None):
        self._write(_CASET, ustruct.pack(">HH", x0, x1))
        self._write(_PASET, ustruct.pack(">HH", y0, y1))
        if data is None:
            return self._read(_RAMRD, (x1 - x0 + 1) * (y1 - y0 + 1) * 3)

    def _read(self, command, count):
        self.dc(0)
        self.cs(0)
        self.spi.write(bytearray([command]))
        data = self.spi.read(count)
        self.cs(1)
        return data

    def pixel(self, x, y, color=None):
        if color is None:
            r, b, g = self._readblock(x, y, x, y)
            return color565(r, g, b)
        if not 0 <= x < self.width or not 0 <= y < self.height:
            return
        self._writeblock(x, y, x, y, ustruct.pack(">H", color))

    def fill_rectangle(self, x, y, w, h, color=None):
        x = min(self.width - 1, max(0, x))
        y = min(self.height - 1, max(0, y))
        w = min(self.width - x, max(1, w))
        h = min(self.height - y, max(1, h))
        if color:
            color = ustruct.pack(">H", color)
        else:
            color = self._colormap[0:2] #background
        for i in range(_CHUNK):
            self._buf[2*i]=color[0]; self._buf[2*i+1]=color[1]
        chunks, rest = divmod(w * h, _CHUNK)
        self._writeblock(x, y, x + w - 1, y + h - 1, None)
        if chunks:
            for count in range(chunks):
                self._data(self._buf)
        if rest != 0:
            mv = memoryview(self._buf)
            self._data(mv[:rest*2])

    def erase(self):
        self.fill_rectangle(0, 0, self.width, self.height)

    def blit(self, bitbuff, x, y, w, h):
        x = min(self.width - 1, max(0, x))
        y = min(self.height - 1, max(0, y))
        w = min(self.width - x, max(1, w))
        h = min(self.height - y, max(1, h))
        chunks, rest = divmod(w * h, _CHUNK)
        self._writeblock(x, y, x + w - 1, y + h - 1, None)
        written = 0
        for iy in range(h):
            for ix in range(w):
                index = ix+iy*w - written
                if index >=_CHUNK:
                    self._data(self._buf)
                    written += _CHUNK
                    index   -= _CHUNK
                c = bitbuff.pixel(ix,iy)
                self._buf[index*2] = self._colormap[c*2]
                self._buf[index*2+1] = self._colormap[c*2+1]
        rest = w*h - written
        if rest != 0:
            mv = memoryview(self._buf)
            self._data(mv[:rest*2])

    def chars(self, str, x, y):
        str_w  = self._font.get_width(str)
        div, rem = divmod(self._font.height(),8)
        nbytes = div+1 if rem else div
        buf = bytearray(str_w * nbytes)
        pos = 0
        for ch in str:
            glyph, char_w = self._font.get_ch(ch)
            for row in range(nbytes):
                index = row*str_w + pos
                for i in range(char_w):
                    buf[index+i] = glyph[nbytes*i+row]
            pos += char_w
        fb = framebuf.FrameBuffer(buf,str_w, self._font.height(), framebuf.MONO_VLSB)
        self.blit(fb,x,y,str_w,self._font.height())
        return x+str_w

    def scroll(self, dy):
        self._scroll = (self._scroll + dy) % self.height
        self._write(_VSCRSADD, ustruct.pack(">H", self._scroll))

    def next_line(self, cury, char_h):
        global scrolling
        if not self.scrolling:
            res = cury + char_h
            self.scrolling = (res >= self.height)
        if self.scrolling:
            self.scroll(char_h)
            res = (self.height - char_h + self._scroll)%self.height
            self.fill_rectangle(0, res, self.width, self._font.height())
        return res

    def write(self, text): #does character wrap, compatible with stream output
        curx = self._x; cury = self._y
        char_h = self._font.height()
        width = 0
        written = 0
        for pos, ch in enumerate(text):
            if ch == '\n':
                if pos>0:
                    self.chars(text[written:pos],curx,cury)
                curx = 0; written = pos+1; width = 0
                cury = self.next_line(cury,char_h)
            else:
                char_w = self._font.get_width(ch)
                if curx + width + char_w >= self.width:
                    self.chars(text[written:pos], curx,cury)
                    curx = 0 ; written = pos; width = char_h
                    cury = self.next_line(cury,char_h)
                else:
                    width += char_w
        if written<len(text):
            curx = self.chars(text[written:], curx,cury)
        self._x = curx; self._y = cury


    def print(self, text): #does word wrap, leaves self._x unchanged
        cury = self._y; curx = self._x
        char_h = self._font.height()
        char_w = self._font.max_width()
        lines = text.split('\n')
        for line in lines:
            words = line.split(' ')
            for word in words:
                if curx + self._font.get_width(word) >= self.width:
                    curx = self._x; cury = self.next_line(cury,char_h)
                    while self._font.get_width(word) > self.width:
                        self.chars(word[:self.width//char_w],curx,cury)
                        word = word[self.width//char_w:]
                        cury = self.next_line(cury,char_h)
                if len(word)>0:
                    curx = self.chars(word+' ', curx,cury)
            curx = self._x; cury = self.next_line(cury,char_h)
        self._y = cury

import tt14

RED = const(0XF800)  # (255, 0, 0)
GREEN = const(0X07E0)  # (0, 255, 0)
BLUE = const(0X001F)  # (0, 0, 255)
YELLOW = const(0XFFE0)  # (255, 255, 0)
FUCHSIA = const(0XF81F)  # (255, 0, 255)
AQUA = const(0X07FF)  # (0, 255, 255)
MAROON = const(0X8000)  # (128, 0, 0)
DARKGREEN = const(0X0400)  # (0, 128, 0)
NAVY = const(0X0010)  # (0, 0, 128)
TEAL = const(0X0410)  # (0, 128, 128)
PURPLE = const(0X8010)  # (128, 0, 128)
OLIVE = const(0X8400)  # (128, 128, 0)
ORANGE = const(0XFC00)  # (255, 128, 0)
DEEP_PINK = const(0XF810)  # (255, 0, 128)
CHARTREUSE = const(0X87E0)  # (128, 255, 0)
SPRING_GREEN = const(0X07F0)  # (0, 255, 128)
INDIGO = const(0X801F)  # (128, 0, 255)
DODGER_BLUE = const(0X041F)  # (0, 128, 255)
CYAN = const(0X87FF)  # (128, 255, 255)
PINK = const(0XFC1F)  # (255, 128, 255)
LIGHT_YELLOW = const(0XFFF0)  # (255, 255, 128)
LIGHT_CORAL = const(0XFC10)  # (255, 128, 128)
LIGHT_GREEN = const(0X87F0)  # (128, 255, 128)
LIGHT_SLATE_BLUE = const(0X841F)  # (128, 128, 255)
WHITE = const(0XFFFF)  # (255, 255, 255)
BLACK = const(0)

text = 'Fine'
spi = SPI(0, baudrate=32000000, sck=Pin(2), mosi=Pin(3), miso=Pin(4),) #SPI(2, baudrate=20000000, miso=Pin(19),mosi=Pin(23), sck=Pin(18))
display = ILI9341(spi, cs=Pin(5), dc=Pin(7), rst=Pin(6), w=320, h=240, r=3)
display.erase()
display.set_color(RED,0)
display.set_font(tt14)
display.set_pos(0,0)
display.print(text)
display.set_pos(0,20)
display.print(text)
display.set_pos(40,20)
display.print(text)
for x in range(0,100):
    display.pixel(2*x,x,BLUE)

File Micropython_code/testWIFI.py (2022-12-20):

import board
import busio
from digitalio import DigitalInOut

from adafruit_esp32spi import adafruit_esp32spi
import adafruit_requests as requests

print("Raspberry Pi RP2040 - ESP32SPI hardware test")

esp32_cs = DigitalInOut(board.GP13)
esp32_ready = DigitalInOut(board.GP14)
esp32_reset = DigitalInOut(board.GP15)

spi = busio.SPI(board.GP10, board.GP11, board.GP12)
esp = adafruit_esp32spi.ESP_SPIcontrol(spi, esp32_cs, esp32_ready, esp32_reset)

if esp.status == adafruit_esp32spi.WL_IDLE_STATUS:
    print("ESP32 found and in idle mode")
print("Firmware vers.", esp.firmware_version)
print("MAC addr:", [hex(i) for i in esp.MAC_address])

for ap in esp.scan_networks():
    print("\t%s\t\tRSSI: %d" % (str(ap['ssid'], 'utf-8'), ap['rssi']))

print("Done!")

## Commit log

2022-11-16 Add library and hierarchical schematic
    [Final_project - Copy.kicad_pcb, Final_project.kicad_sch, wifi_module.kicad_sch]
2022-11-16 added audiojack
    [Final_project.kicad_sch, audiojack.kicad_sch]
2022-11-18 Complete wifi module airlift
    [Final_project.kicad_sch, wifi_module.kicad_sch]
2022-11-18 Complete pinouts on main
    [Final_project.kicad_sch, wifi_module.kicad_sch]
2022-11-18 assigned footprints to audiojack caps
    [Final_project.kicad_sch, audiojack.kicad_sch]
2022-11-18 Add light sensing sheet
    [Final_project.kicad_sch, light_sensing.kicad_sch, wifi_module.kicad_sch]
2022-11-26 Add miniproj parts, begin photosensing circuit
    [Final_project.kicad_sch, light_sensing.kicad_sch]
2022-11-26 added copy of light sensing module
    [Final_project (copy).kicad_sch, light_sensing.kicad_sch]
2022-11-27 Add pinouts for connectors
    [Final_project (copy).kicad_sch]
2022-11-27 added a footprint to the current library and uploaded Micropython_code
2022-11-27 Add horizontal pin connect
    [Final_project (copy).kicad_sch]
2022-11-28 started layout
    [Final_project (copy).kicad_sch, Final_project - Copy - HDMI_audiojack3.kicad_sch, Final_project - Copy.kicad_pcb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]
2022-11-28 Fix 3V3 label, fix USB footprint, layout begin
    [Final_project.kicad_pcb, Final_project.kicad_sch, wifi_module.kicad_sch]
2022-11-28 Layout continued, delete header
    [Final_project.kicad_pcb, Final_project.kicad_sch]
2022-11-28 almost finished layout
    [Final_project.kicad_pcb, Final_project.kicad_sch, Final_project_audiojack3.kicad_sch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]
2022-11-28 updated pcb file
    [Final_project.kicad_pcb]
2022-11-28 finishing up layout, a few steps remained
    [Final_project.kicad_pcb, Final_project.kicad_sch]
2022-11-29 Add 3d, fixing vias and layout issues
    [3382g-001-xxx.stp, ABM10.STP, ABS06-107.STP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]
2022-11-29 fixed several problems
    [Final_project.kicad_pcb]
2022-11-29 rewired some GND pins
    [Final_project.kicad_pcb]
2022-11-29 Add final layout with no connector
    [Final_project_no_connector.kicad_pcb]
2022-11-30 Clean layout and ESP32 footprint
    [Final_project_no_connector.kicad_pcb]
2022-11-30 Fix trace sizing power
    [Final_project_no_connector.kicad_pcb]
2022-11-30 Complete layout for no connectors add silkscreens
    [Final_project_no_connector-B_Cu.gbl, Final_project_no_connector-B_Mask.gbs, Final_project_no_connector-B_Paste.gbp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]

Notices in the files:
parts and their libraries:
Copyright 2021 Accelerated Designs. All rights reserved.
